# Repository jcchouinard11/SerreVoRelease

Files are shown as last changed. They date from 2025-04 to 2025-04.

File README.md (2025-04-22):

# SerreVo - Système de Gestion de Serre Intelligente

## Présentation
SerreVo est un projet de gestion automatisée de serre basé sur l'ESP32 et Arduino. Il permet le suivi et le contrôle des paramètres environnementaux pour optimiser la croissance des plantes.

## Fonctionnalités
- Surveillance en temps réel de la température, humidité
- Transmission des données via Bluetooth
- Interface web pour visualisation et réglages

## Structure du Répertoire
- **Documentation/** : Fichiers et guides du projet (Fichiers PCB)
- **Release/** : Code et fichiers finaux pour le projet (Codes serveur et controleurs)
- **.gitignore** : Fichiers à exclure du versionnement

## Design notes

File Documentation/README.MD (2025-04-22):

# README

## Description
Ce projet concerne le développement et la gestion d'un système centralisé pour la serre automatique. Il inclut la conception des schémas et circuits imprimés (PCB) ainsi que la gestion des tests unitaires.

---

## Structure des fichiers

### Dossiers
- `OutputReleaseV1SerreVo` : Contient la version de sortie du projet.

### Documentation et Tests
- `plan_de_tests_unitairesSerreVO.xlsx` : Plan détaillé des tests unitaires pour vérifier le bon fonctionnement des différentes parties du système.
- `README.md` : Ce fichier, expliquant la structure et l'utilisation du projet.

---

## Utilisation

1. Vérifier et modifier les schémas électroniques si nécessaire dans `SerreVo_Controller` et `SerreVo`.
2. Consulter `plan_de_tests_unitairesSerreVO.xlsx` tests unitaires pour s'assurer le bon fonctionnement du projet. 
3. Utiliser `OutputReleaseV1SerreVo` pour récupérer la version finale du projet.

---

## Remarques
- `SerreVo_Controller` et `SerreVo` contiennent les fichiers de conception des circuits imprimés.
- Assurez-vous que toutes les modifications aux PCB respectent les contraintes électriques et mécaniques du projet.
- Le plan de tests doit être suivi rigoureusement avant toute validation finale.

---

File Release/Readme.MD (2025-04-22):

# SerreVoRElease - Gestion de Serre avec ESP32 

## Description
SerreVo est un projet de gestion automatisée de serre utilisant un ESP32 et Arduino. Ce projet inclut également des fichiers de conception de PCB pour l'intégration matérielle finale.

## Structure du Répertoire
- **CodesControleur/** : Contient le firmware Arduino pour l'ESP32 Du controleur principal.
- **CodesEtFichiersServeurs/** : Fichiers de de la partie serveur.
- **.gitignore** : Fichier de configuration Git pour ignorer certains fichiers.
- **README.md** : Documentation du projet.

## Auteur
Projet SerreVo - Automatisation de serre intelligente.

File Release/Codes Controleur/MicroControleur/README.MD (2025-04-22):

# 📟 Projet de Gestion de Capteurs avec Affichage LVGL et BLE

Ce projet est une implémentation sur microcontrôleur permettant la gestion de plusieurs capteurs (température et humidité) via des bus I2C multiplexés, l'affichage des données sur un écran tactile avec LVGL, ainsi que la transmission Bluetooth Low Energy (BLE).

## 📌 Fonctionnalités

- **Gestion de capteurs multiples** : 
  - Supporte plusieurs bus I2C via `FlexWire`
  - Gestion de multiplexeurs pour l'ajout de plusieurs capteurs
  - Lecture des données depuis des capteurs `Adafruit_seesaw` et `SHT31`
- **Interface graphique avec LVGL** :
  - Affichage des mesures sur un écran TFT
  - Gestion tactile avec `XPT2046`
- **Communication BLE** :
  - Serveur BLE pour l'envoi des mesures vers un appareil mobile ou un ordinateur
  - Publicité BLE avec UUID spécifique
- **Gestion des tâches concurrentes** :
  - Synchronisation des accès aux capteurs avec `Semaphore`
  - Mise à jour de l'affichage et des données via `FreeRTOS`

## 🛠 Matériel Utilisé

- Microcontrôleur compatible avec **Arduino**
- Capteur de température et d'humidité **SHT31**
- Capteurs capacitifs **Adafruit Seesaw**
- Multiplexeur **I2C (TCA9548A ou équivalent)**
- Écran **TFT 240x320** avec contrôleur **ILI9341**
- Contrôleur tactile **XPT2046**
- Module **Bluetooth Low Energy (BLE)** intégré ou externe

## 🏗 Bibliothèques Requises

Avant de compiler, assure-toi d'installer les bibliothèques suivantes dans **Arduino IDE** ou **PlatformIO** :

- `FlexWire`
- `lvgl`
- `Adafruit_seesaw`
- `Adafruit_SHT31`
- `XPT2046_Touchscreen`
- `TFT_eSPI`
- `BLEDevice`

## 🚀 Installation et Compilation

1. **Cloner le projet** :
   ```sh
   git clone https://github.com/ton-repo/gestion-capteurs.git
   cd gestion-capteurs

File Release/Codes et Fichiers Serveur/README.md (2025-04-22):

# README

## Description
Cette partie du projet s'occupe de récupérer les donnés envoyés par BLE grâce à un bridge BLE/MQTT et les stocker dans une base de donné. Ces donnés sont alors afficher sur une page web à l'aide de Grafana
---

## Structure des fichiers

### Scripts Python
- `ScriptMQTT/MQTT_decodage.py` : Code principal qui récupère les données MQTT et les insère dans la base de données.
- `Grafana/dashboardSerreVO.json` : Ficher de dashboard pour import

### Bases de données SQLite
- `SerreVo` : Fichier de base de données principal utilisé pour stocker les informations.

### Documentation
- `README.md` : Ce fichier, expliquant la structure et l'utilisation du projet.

---

## Utilisation

1. Assurez-vous que votre broker MQTT est opérationnel et que le bridge BLE/MQTT envoie correctement les données.
2. Exécutez `MQTT_decodage.py` dans un terminal pour collecter et stocker les données.
3. Vous pourrez visualiser les données grâce à SQLite  studio ou Grafana.

---

---

Aidé par ChatGPT

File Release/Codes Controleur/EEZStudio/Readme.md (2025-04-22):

# Repertoire des fichiers EEZStudio 

Repertoire avec les fichiers de "UI" pour afficher et modifier l'écran LVGL

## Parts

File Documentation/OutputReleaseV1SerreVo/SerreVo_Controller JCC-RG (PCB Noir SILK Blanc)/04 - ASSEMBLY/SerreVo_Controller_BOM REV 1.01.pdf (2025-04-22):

Board | 1
Cours | 01

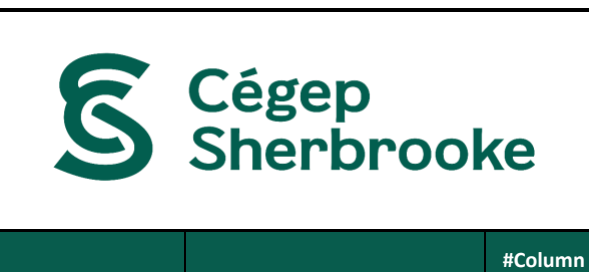
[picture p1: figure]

Item Number | Designator | Layer | Description | Comment | Package / Case | Supplier 1 | Supplier Part Number 1 | Quantity | Quantity Total | #Column Name Error:' Note
| C1, C7 | Top | CAP CER 0.1UF 16V X7R 0603 | 0.1 µF | 0603, 0603 (1608 Metric) | DigiKey | 478-KGM15AR71C104MMCT-ND, 399-5784-2-ND | 2 | 2
| C2, C5, C8, C9 | Top | CAP CER 0.012UF 16V X7R 0603 | 0.012 µF | 0603 (1608 Metric) | DigiKey | 311-3370-1-ND | 4 | 4
| C3 | Top | CAP ALUM 100UF 20% 10V SMD | 100 µF | Radial, Can - SMD | DigiKey | PCE3867CT-ND | 1 | 1
| C4 | Top | CAP CER 1UF 16V X7R 0603 | 1 µF | 0603 (1608 Metric) | DigiKey | 399-17719-1-ND | 1 | 1
| C6 | Top | CAP CER 22UF 6.3V X5R 0603 | 22µF | 0603 (1608 Metric) | DigiKey | 478-10812-1-ND | 1 | 1
| C10, C11 | Top | CAP CER 4.7UF 16V X6S 0603 | 4.7 µF | 0603 (1608 Metric) | DigiKey | 490-13362-1-ND | 2 | 2
| C12, C13, C14, C15, C16, C17, C18, C19 | Bottom | CAP CER 47UF 6.3V X5R 0603 | 47µF | 0603 (1608 Metric) | DigiKey | 478-11180-1-ND | 8 | 8
| D1 | Top | TVS DIODE 5.25V 17V SOT666 | USBLC6-2P6 | | | | 1 | 1
| D2 | Top | LED GREEN DIFFUSED 0603 SMD | Green | 0603 (1608 Metric) | DigiKey | 511-1579-1-ND | 1 | 1
| D3 | Top | LED RED DIFFUSED 1608 SMD | Red | 0603 (1608 Metric) | DigiKey | SML-D12U1WT86CT-ND | 1 | 1
| J1 | Top | CONN RCP USB2.0 TYP C 24P SMD RA | Usb-C | | | | 1 | 1
| J2, J3, J4, J5 | Top | Jack Modular Connector 8p8c _RJ45, Ethernet_ Vertical Unshielded Cat6 | SS-60000-007 | | | | 4 | 4
| J6 | Top | Connector Header Through Hole 10 position 0.098 (2.50mm) | B10B-XH-A(LF)(SN) | | | | 1 | 1
| J7 | Top | | B4B-XH-A | | | | 1 | 1
| Q1 | Top | MOSFET P-CHA 60V 720MW SOT23 | DMP6350S-7 | | | | 1 | 1
| R1, R2 | Top | RES 5.1KΩ 1.00% 0.1W 0603 | 5.1kohms | | | | 2 | 2
| R3, R4, R17, R18, R19, R20, R21, R22, R24, R25 | Top | RES SMD 30 OHM 5% 1/4W 0603 | 30 Ohms | 0603 (1608 Metric) | DigiKey | RHM30DCT-ND | 10 | 10

# Bill of Material

SerreVo Controleur | Concepteur Principal Jean-Christophe Chouinard
Projet TSO 2025 | Date du projet 2025-02-04
Technologies du génie électrique Département | Date de génération du BOM 2025-02-11
Révision 1.01 | Heure de génération du BOM 11:27
Nombre de PCB 1 | Variant None

Item Number | Designator | Layer | Description | Comment | Package / Case | Supplier 1 | Supplier Part Number 1 | Quantity | Quantity Total | #Column Name Error:' Note
| R5, R6, R29 | Top | RESA-AS 0603 0R JUMPER 100MW | 0 Ohms | 0603 (1608 Metric) | DigiKey | CR0603AJ/-000EASCT-ND | 3 | 3
| R7, R8, R9, R11, R12, R13, R14, R15, R16 | Top | RES SMD 330 OHM 1% 1/5W 0603 | 330 Ohms | 0603 (1608 Metric) | DigiKey | A129541CT-ND | 9 | 9
| R10, R23, R28 | Top | RES SMD 10K OHM 5% 1/4W 0603 | 10 kOhms | 0603 (1608 Metric) | DigiKey | 541-2817-1-ND | 3 | 3
| R26 | Top | RES SMD 220 OHM 1% 1/10W 0603 | 220 Ohms | 0603 (1608 Metric) | DigiKey | 118-CR0603-FX-2200ELFCT-ND | 1 | 1
| R27 | Top | RES SMD 470 OHM 1% 1/10W 0603 | 470 Ohms | 0603 (1608 Metric) | DigiKey | P470HCT-ND | 1 | 1
| SW1, SW2 | Top | SWITCH TACTILE SPST-NO 0.02A 15V | EVQ-Q2U01W | | | | 2 | 2
| U1 | Top | Bluetooth, WiFi 802.11b/g/n, Bluetooth v5.0 Transceiver Module 2.4GHz Antenna Not Included, U.FL Surface Mount | ESP32-S3-WROOM-1U-N16R8 | | | | 1 | 1
| U2, U3, U5, U6 | Top | Low Voltage I2C/SMBus Accelerator | LTC4311ISC6#TRPBF | | | | 4 | 4
| U4 | Top | No Description Available | R1172S331B-E2-FE | | | | 1 | 1

Commentaires ou instruction spécialies

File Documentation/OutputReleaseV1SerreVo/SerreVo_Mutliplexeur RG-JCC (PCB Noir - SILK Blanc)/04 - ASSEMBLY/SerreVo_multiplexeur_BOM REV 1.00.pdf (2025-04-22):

Board | 1
Cours | 00


Item Number | Designator | Layer | Description | Comment | Package / Case | Supplier 1 | Supplier Part Number 1 | Quantity | Quantity Total | #Column Name Error:' Note
| C1, C2, C3, C4, C8 | Top | CAP ALUM 47UF 20% 35V SMD | 47 µF | | DigiKey | 1572-476SML035MCT-ND | 5 | 5
| C5 | Bottom | CAP CER 1UF 16V X7R 0603 | 1 µF | 0603 (1608 Metric) | DigiKey | 399-17719-1-ND | 1 | 1
| C6, C7 | Bottom | CAP CER 4.7UF 25V X5R 0603 | 4.7 µF | 0603 (1608 Metric) | DigiKey | 1276-1900-1-ND | 2 | 2
| C9 | Top | CAP CER 22UF 6.3V X5R 0603 | 22µF | 0603 (1608 Metric) | DigiKey | 478-10812-1-ND | 1 | 1
| C10 | Top | CAP CER 0.1UF 16V X7R 0603 | 0.1 µF | 0603 (1608 Metric) | DigiKey | 399-5784-2-ND | 1 | 1
| J1, J2, J3, J4, J5 | Top | Jack Modular Connector 8p8c _RJ45, Ethernet_ Vertical Unshielded Cat6 | SS-60000-007 | | | | 5 | 5
| R1 | Top | RES ARRAY 8 RES 33 OHM 2506 | 742C163330JP | 2506, Concave, Long Side Terminals | DigiKey | 742C163330JPCT-ND | 1 | 1
| R2 | Top | RES ARRAY 8 RES 330 OHM 2506 | 742C163331JP | 2506, Concave, Long Side Terminals | DigiKey | 742C163331JPCT-ND | 1 | 1
| R3 | Top | RES SMD 10K OHM 5% 1/4W 0603 | 10 kOhms | 0603 (1608 Metric) | DigiKey | 541-2817-1-ND | 1 | 1
| U1 | Top | IC I2C SW 8CH W/RESET 24TSSOP | TCA9548APWR | | | | 1 | 1
| U2 | Top | No Description Available | R1172S331B-E2-FE | | | | 1 | 1

Commentaires ou instruction spécialies

# Bill of Material

SerrVo_multiplexeur | Concepteur Principal Raphaël Gravel
Projet final | Date du projet 2025-02-04
Technologies du génie électrique Département | Date de génération du BOM 2025-02-11
Révision 1.00 | Heure de génération du BOM 09:09
Nombre de PCB 1 | Variant None

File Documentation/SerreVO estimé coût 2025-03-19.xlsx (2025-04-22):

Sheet: Controleur
Titre du projet
Projet TSO: SerreVO Controleur
Demandeur(s) : Prof responsabe et étudiants
Nicolas Huppé (Jean-Christophe Chouinard / Raphaël Gravel)
Moment où le matériel est NÉCESSAIRE
2025-03-12
Identification des cours qui sont impactés
247-575-SH
Lien(s) vers document de soumission (si applicable)
Liste des éléments associés
Description | Prix unitaire | Taux change (1 par défaut $Can) | Quantité demandée | Total item | Fournisseur | # Modèle pour commande | Hyperlien pour commande (si disponible) ou soumission | Commentaires et/ou autres informations | Colonne réservée pour suivi des commandes
Factory Orginal 3.2" 240*320 ILI9341 | 12.68 $ | 1.00 | 1 | 12.68 $ | Aliexpress |  | https://www.aliexpress.com/item/1005004581389736.html?utparam-url=scene%3Asearch%7Cquery_from%3A
IP68 RJ45 CAT7 Connector Waterproof M23 | 4.04 $ | 1.00 | 4 | 16.16 $ | aliexpress | YPM23-CAT7-B | https://www.aliexpress.com/item/1005007377576378.html?utparam-url=scene%3Asearch%7Cquery_from%3A
Adafruit STEMMA Soil Sensor | 10.74 $ | 1.00 | 4 | 42.96 $ | Adafruit | 4026 | https://www.adafruit.com/product/4026
Câble USB C de 1 m Flat | 11.99 $ | 1.00 | 1 | 11.99 $ | Amazon | B0CPDZBH62 | https://www.amazon.ca/-/fr/gp/product/B0CPDZBH62/ref=ox_sc_act_title_6?smid=A3QJI6T39D7L77
Mâle Femelle Surmoulé Câble USB C type C | 3.71 $ | 1.00 | 2 | 7.42 $ | Alibaba |  | https://www.alibaba.com/product-detail/Speed-3-0-3-1-Panel_1600925654612.html?s=p
SHT30 TEMPERATURE AND HUMIDITY S | 13.60 $ | 1.00 | 1 | 13.60 $ | Adafruit | 5064 | https://www.digikey.ca/en/products/detail/adafruit-industries-llc/5064/14625562?productid=14625562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
Boîte de jonction en plastique ABS étanche à la poussière IP65 | 21.99 $ | 1.00 | 1 | 21.99 $ | Amazon | B07KXSPRGC | https://www.amazon.ca/-/fr/gp/product/B07KXSPRGC/ref=ox_sc_saved_title_6?smid=
Coût PCB Controleur | 60.00 $ | 1.00 | 1 | 60.00 $ | Digikey |  | https://www.digikey.ca/en/mylists/list/ZFMKY3XMLB
Cables variées et connecteurs | 10.00 $ | 1.00 | 1 | 10.00 $
 |  | 1.00 |  | 0.00 $
 |  | 1.00 |  | 0.00 $
 |  | 1.00 |  | 0.00 $
 |  | 1.00 |  | 0.00 $
 |  | 1.00 |  | 0.00 $
 |  | 1.00 |  | 0.00 $
 |  | 1.00 |  | 0.00 $
 |  | 1.00 |  | 0.00 $
 |  | 1.00 |  | 0.00 $
 |  | 1.00 |  | 0.00 $
 |  | 1.00 |  | 0.00 $
 |  | 1.00 |  | 0.00 $
 |  | 1.00 |  | 0.00 $
 |  | 1.00 |  | 0.00 $
 |  | 1.00 |  | 0.00 $
 |  | 1.00 |  | 0.00 $
 |  | 1.00 |  | 0.00 $
 |  | 1.00 |  | 0.00 $
 |  | 1.00 |  | 0.00 $
 |  | 1.00 |  | 0.00 $
 |  |  | Total sans taxes | 196.80 $
 |  |  | Taxe 7% | 13.78 $
 |  |  | Total avec taxes | 210.58 $
 |  |  | Total avec marge 20% | 252.69 $

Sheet: Multiplexeur
Titre du projet
Projet TSO: SerreVO Controleur
Demandeur(s) : Prof responsabe et étudiants
Nicolas Huppé (Jean-Christophe Chouinard / Raphaël Gravel)
Moment où le matériel est NÉCESSAIRE
2025-03-12
Identification des cours qui sont impactés
247-575-SH
Lien(s) vers document de soumission (si applicable)
Liste des éléments associés
Description | Prix unitaire | Taux change (1 par défaut $Can) | Quantité demandée | Total item | Fournisseur | # Modèle pour commande | Hyperlien pour commande (si disponible) ou soumission | Commentaires et/ou autres informations | Colonne réservée pour suivi des commandes
IP68 RJ45 CAT7 Connector Waterproof M23 | 4.04 $ | 1.00 | 5 | 20.20 $ | aliexpress | YPM23-CAT7-B | https://www.aliexpress.com/item/1005007377576378.html?utparam-url=scene%3Asearch%7Cquery_from%3A
Boîte de jonction en plastique ABS étanche à la poussière IP65 | 21.99 $ | 1.00 | 1 | 21.99 $ | Amazon | B07KXSPRGC | https://www.amazon.ca/-/fr/gp/product/B07KXSPRGC/ref=ox_sc_saved_title_6?smid=
Cout PCB Multiplexeur | 30.00 $ | 1.00 | 1 | 30.00 $ | Digikey |  | https://www.digikey.ca/en/mylists/list/KLJ95604RC
Cables variées et connecteurs | 5.00 $ | 1.00 | 1 | 5.00 $
 |  | 1.00 |  | 0.00 $
 |  | 1.00 |  | 0.00 $
 |  | 1.00 |  | 0.00 $
 |  | 1.00 |  | 0.00 $
 |  | 1.00 |  | 0.00 $
 |  | 1.00 |  | 0.00 $
 |  | 1.00 |  | 0.00 $
 |  | 1.00 |  | 0.00 $
 |  | 1.00 |  | 0.00 $
 |  | 1.00 |  | 0.00 $
 |  | 1.00 |  | 0.00 $
 |  | 1.00 |  | 0.00 $
 |  | 1.00 |  | 0.00 $
 |  | 1.00 |  | 0.00 $
 |  | 1.00 |  | 0.00 $
 |  | 1.00 |  | 0.00 $
 |  | 1.00 |  | 0.00 $
 |  | 1.00 |  | 0.00 $
 |  | 1.00 |  | 0.00 $
 |  | 1.00 |  | 0.00 $
 |  |  | Total sans taxes | 77.19 $
 |  |  | Taxe 7% | 5.40 $
 |  |  | Total avec taxes | 82.59 $
 |  |  | Total avec marge 20% | 99.11 $

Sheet: Capteurs
Titre du projet
Projet TSO: SerreVO Controleur
Demandeur(s) : Prof responsabe et étudiants
Nicolas Huppé (Jean-Christophe Chouinard / Raphaël Gravel)
Moment où le matériel est NÉCESSAIRE
2025-03-12
Identification des cours qui sont impactés
247-575-SH
Lien(s) vers document de soumission (si applicable)
Liste des éléments associés
Description | Prix unitaire | Taux change (1 par défaut $Can) | Quantité demandée | Total item | Fournisseur | # Modèle pour commande | Hyperlien pour commande (si disponible) ou soumission | Commentaires et/ou autres informations | Colonne réservée pour suivi des commandes
Adafruit STEMMA Soil Sensor | 10.74 $ | 1.00 | 1 | 10.74 $ | Adafruit | 4026 | https://www.adafruit.com/product/4026
Cables variées et connecteurs | 2.00 $ | 1.00 | 1 | 2.00 $
 |  | 1.00 |  | 0.00 $
 |  | 1.00 |  | 0.00 $
 |  | 1.00 |  | 0.00 $
 |  | 1.00 |  | 0.00 $
 |  | 1.00 |  | 0.00 $
 |  | 1.00 |  | 0.00 $
 |  | 1.00 |  | 0.00 $
 |  | 1.00 |  | 0.00 $
 |  | 1.00 |  | 0.00 $
 |  | 1.00 |  | 0.00 $
 |  | 1.00 |  | 0.00 $
 |  | 1.00 |  | 0.00 $
 |  | 1.00 |  | 0.00 $
 |  | 1.00 |  | 0.00 $
 |  | 1.00 |  | 0.00 $
 |  | 1.00 |  | 0.00 $
 |  | 1.00 |  | 0.00 $
 |  | 1.00 |  | 0.00 $
 |  | 1.00 |  | 0.00 $
 |  | 1.00 |  | 0.00 $
 |  |  | Total sans taxes | 12.74 $
 |  |  | Taxe 7% | 0.89 $
 |  |  | Total avec taxes | 13.63 $
 |  |  | Total avec marge 20% | 16.36 $

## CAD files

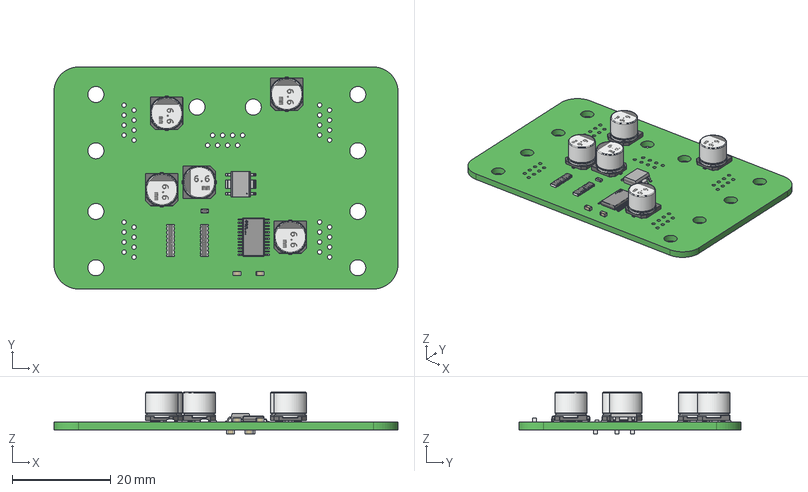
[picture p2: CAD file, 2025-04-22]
Documentation/OutputReleaseV1SerreVo/SerreVo_Mutliplexeur RG-JCC (PCB Noir - SILK Blanc)/05 - 3D MODEL/SerreVo_multiplexeur_PCB REV 1.00.step
69.8 x 45.1 x 8.48 mm
0603 cap x 5
0603 resistor
CAP ALSMD - 6.6 x 6.6 x 6.1 x 5
RESNET - 2506 Concave x 2
BODY-TSSOP
LEAD-TSSOP x 24
Texas Logo Yury
Texas Logo Yury - 1

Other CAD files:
Documentation/OutputReleaseV1SerreVo/SerreVo_Mutliplexeur RG-JCC (PCB Noir - SILK Blanc)/05 - 3D MODEL/SerreVo_multiplexeur_PCB REV 1.00.x_t

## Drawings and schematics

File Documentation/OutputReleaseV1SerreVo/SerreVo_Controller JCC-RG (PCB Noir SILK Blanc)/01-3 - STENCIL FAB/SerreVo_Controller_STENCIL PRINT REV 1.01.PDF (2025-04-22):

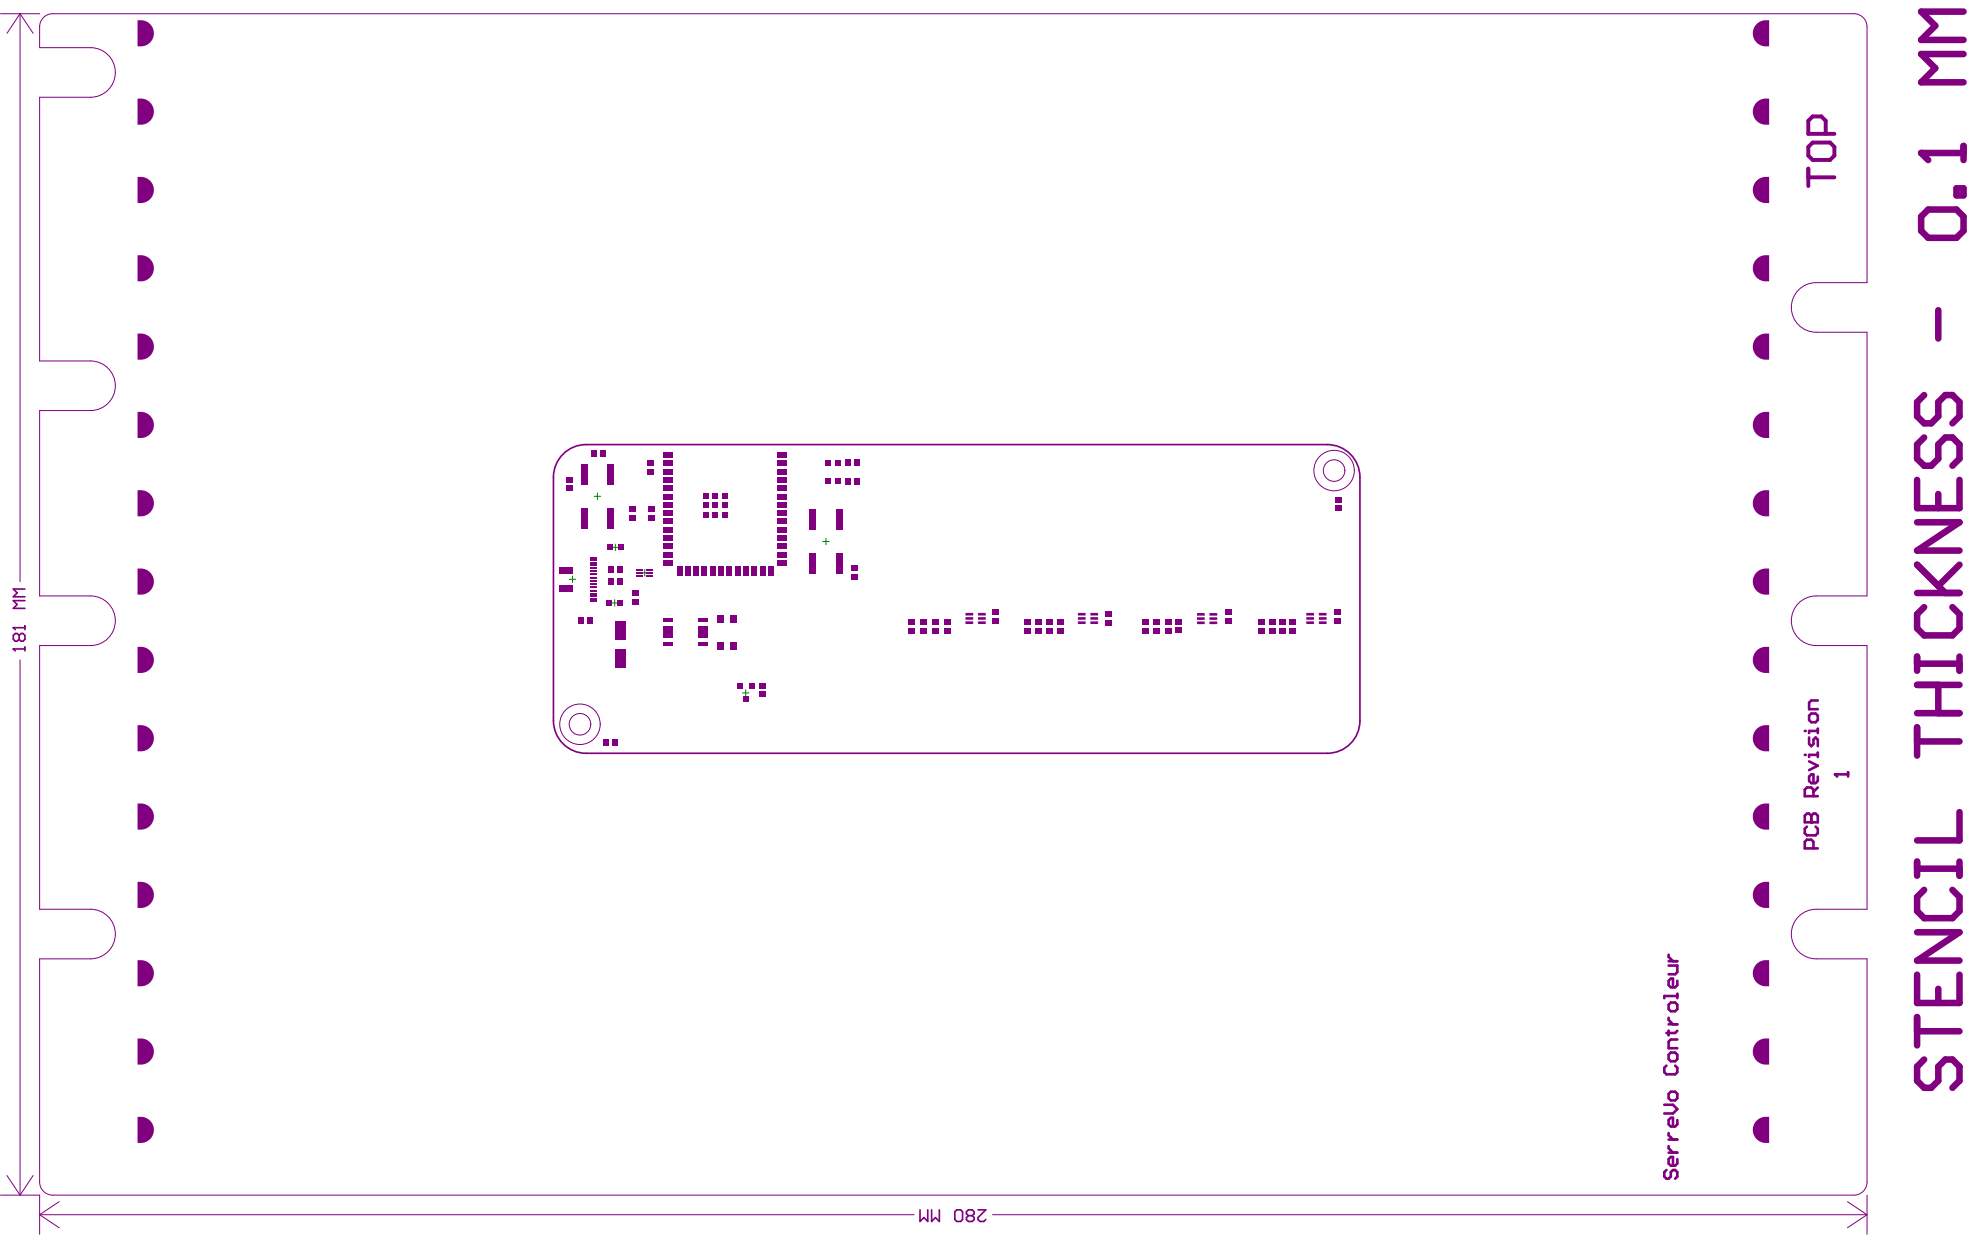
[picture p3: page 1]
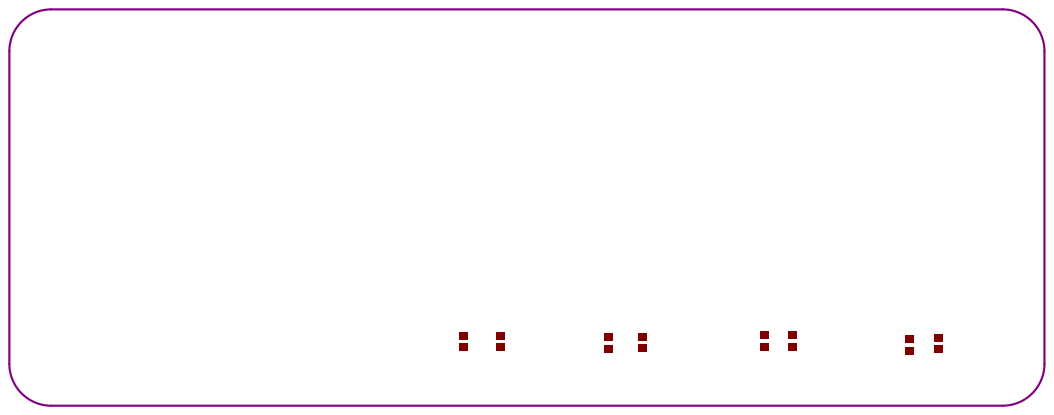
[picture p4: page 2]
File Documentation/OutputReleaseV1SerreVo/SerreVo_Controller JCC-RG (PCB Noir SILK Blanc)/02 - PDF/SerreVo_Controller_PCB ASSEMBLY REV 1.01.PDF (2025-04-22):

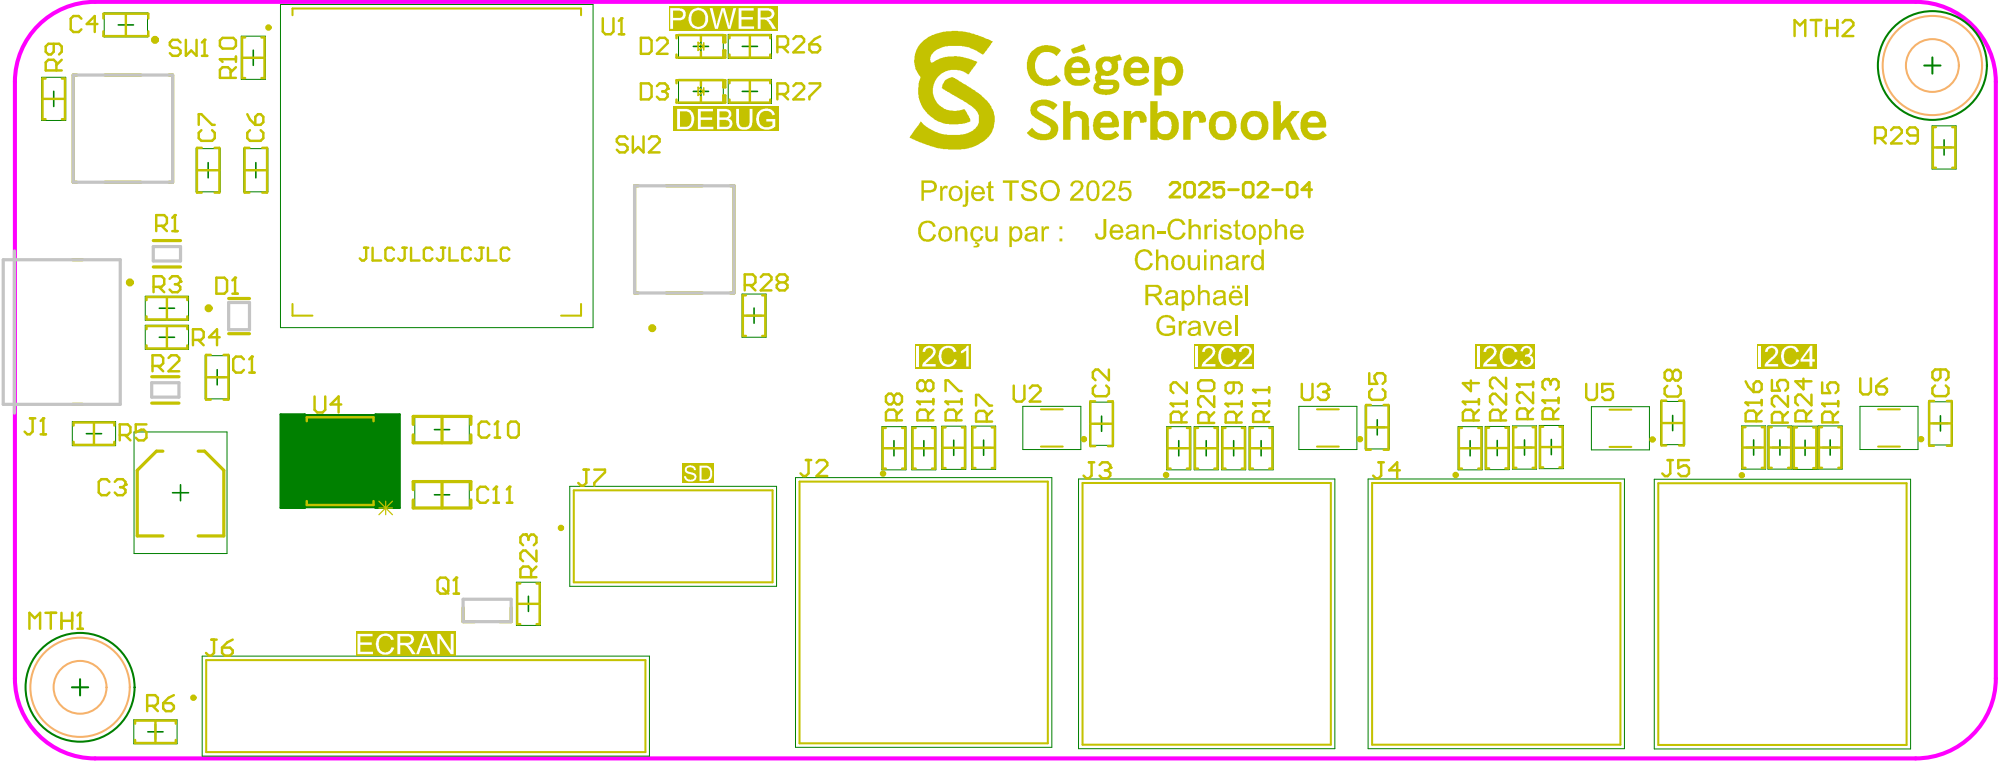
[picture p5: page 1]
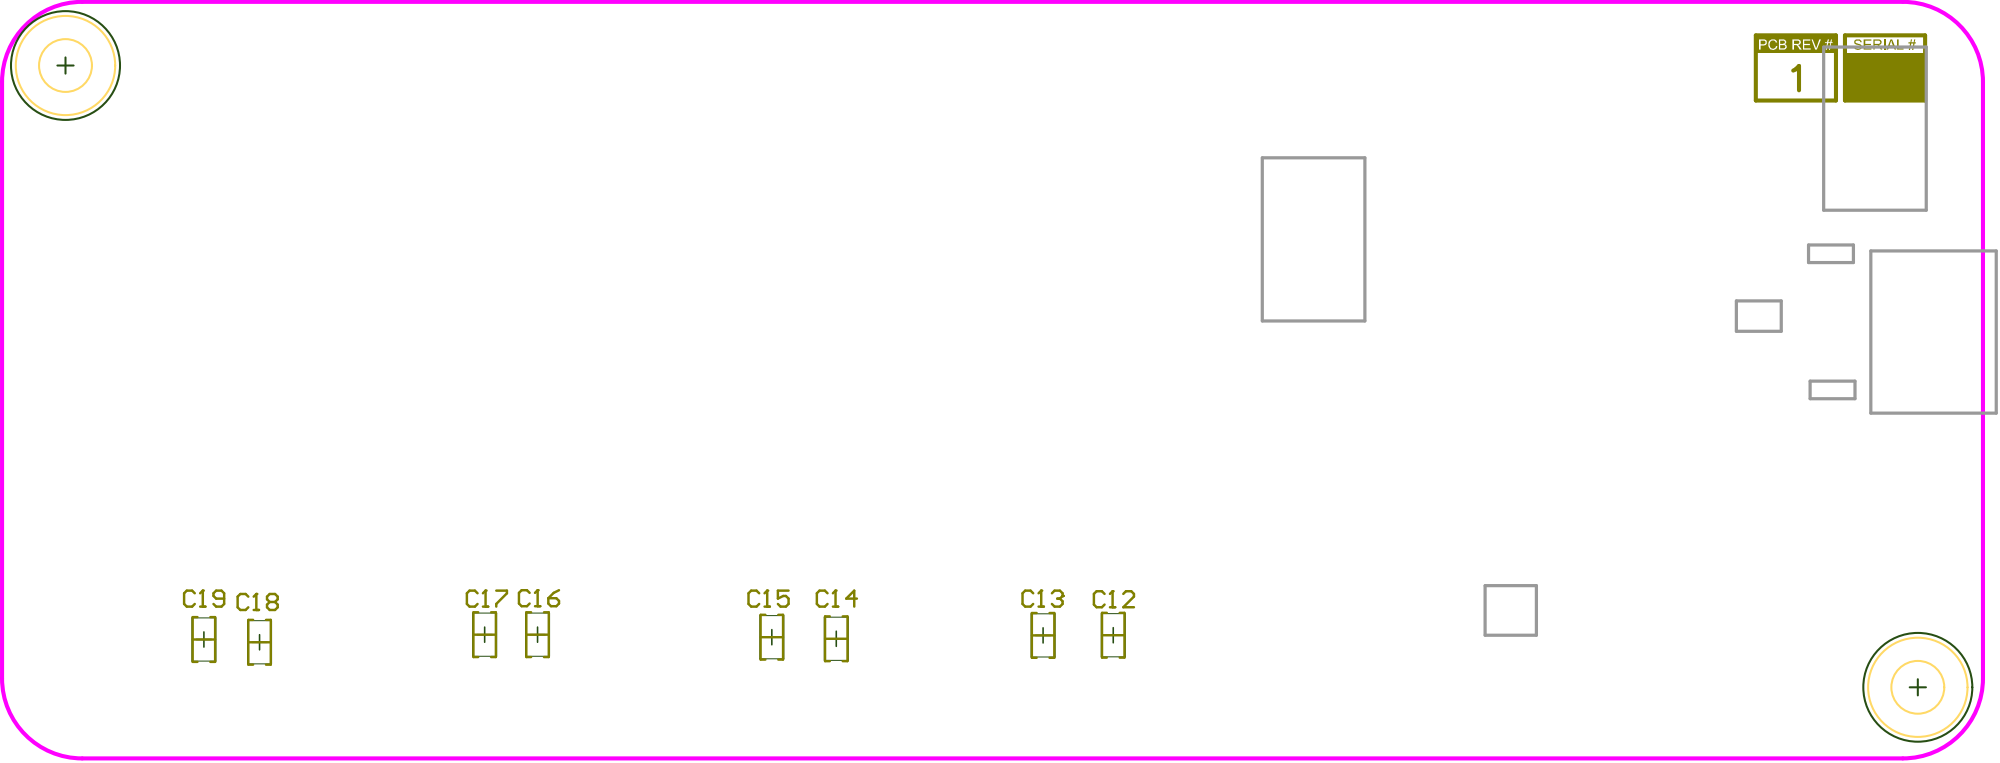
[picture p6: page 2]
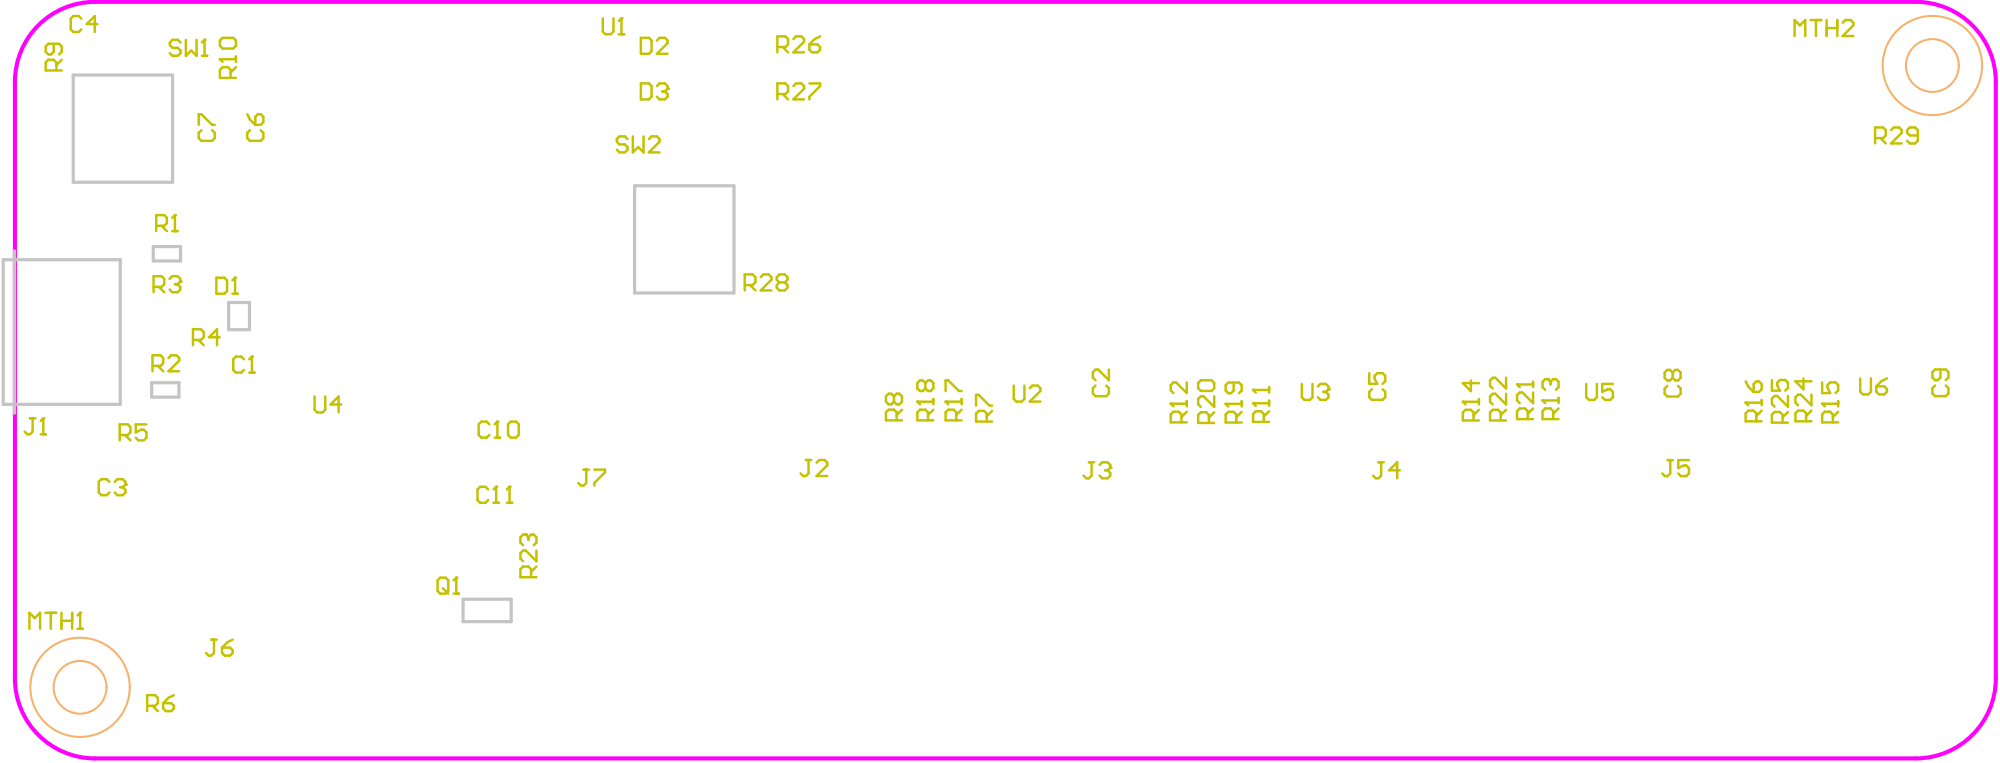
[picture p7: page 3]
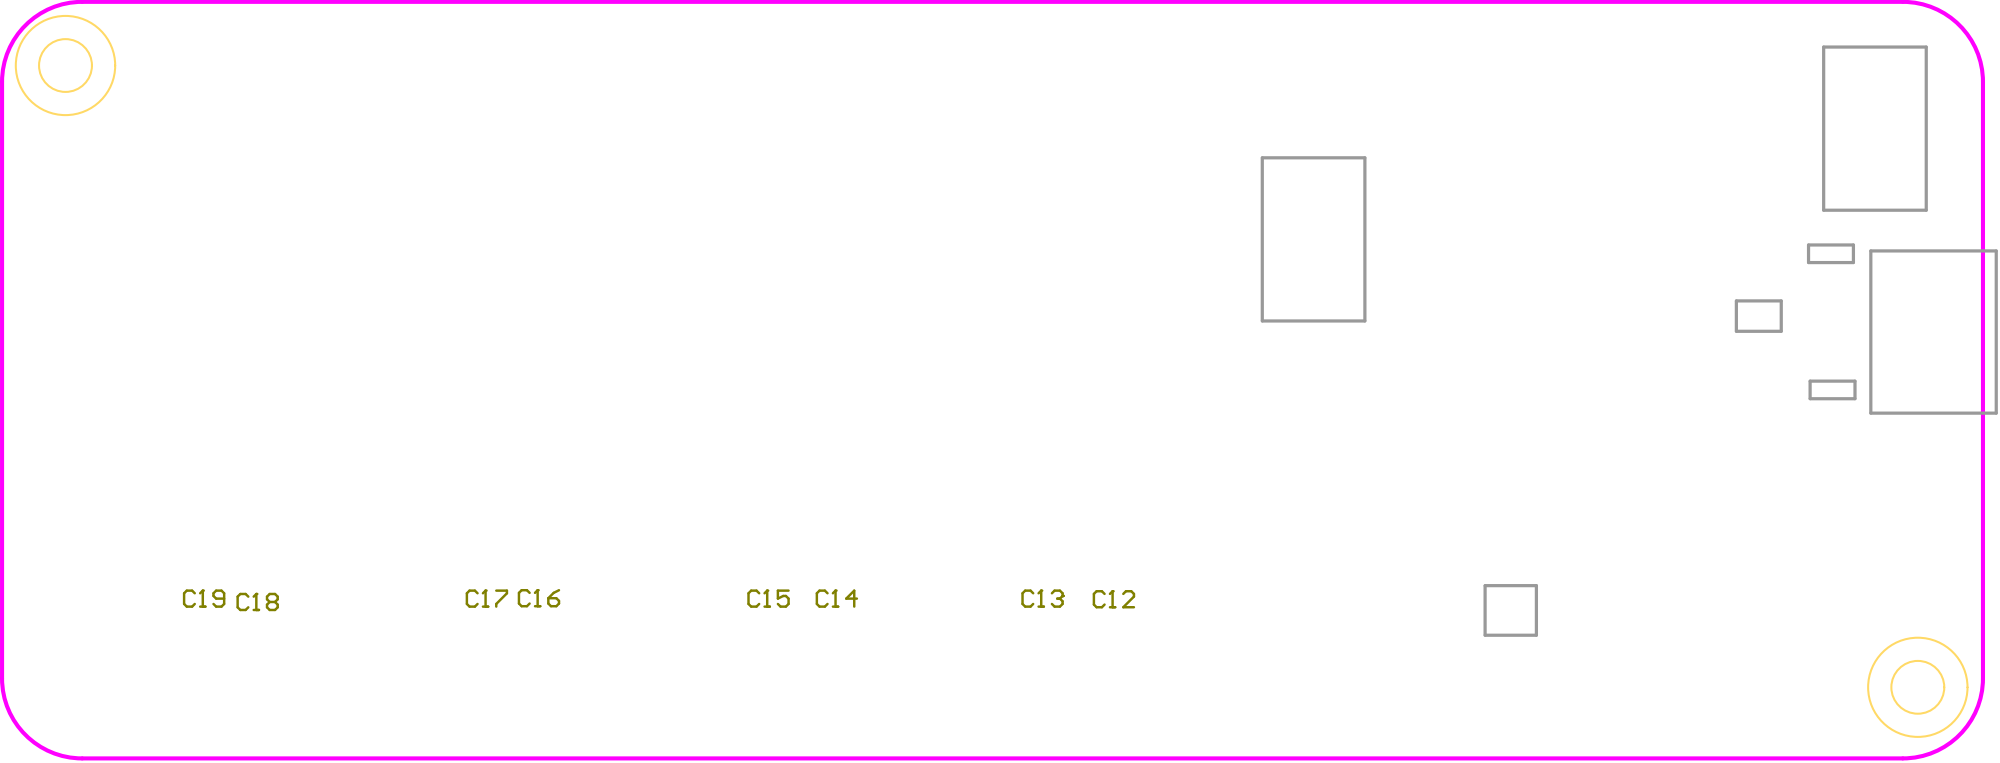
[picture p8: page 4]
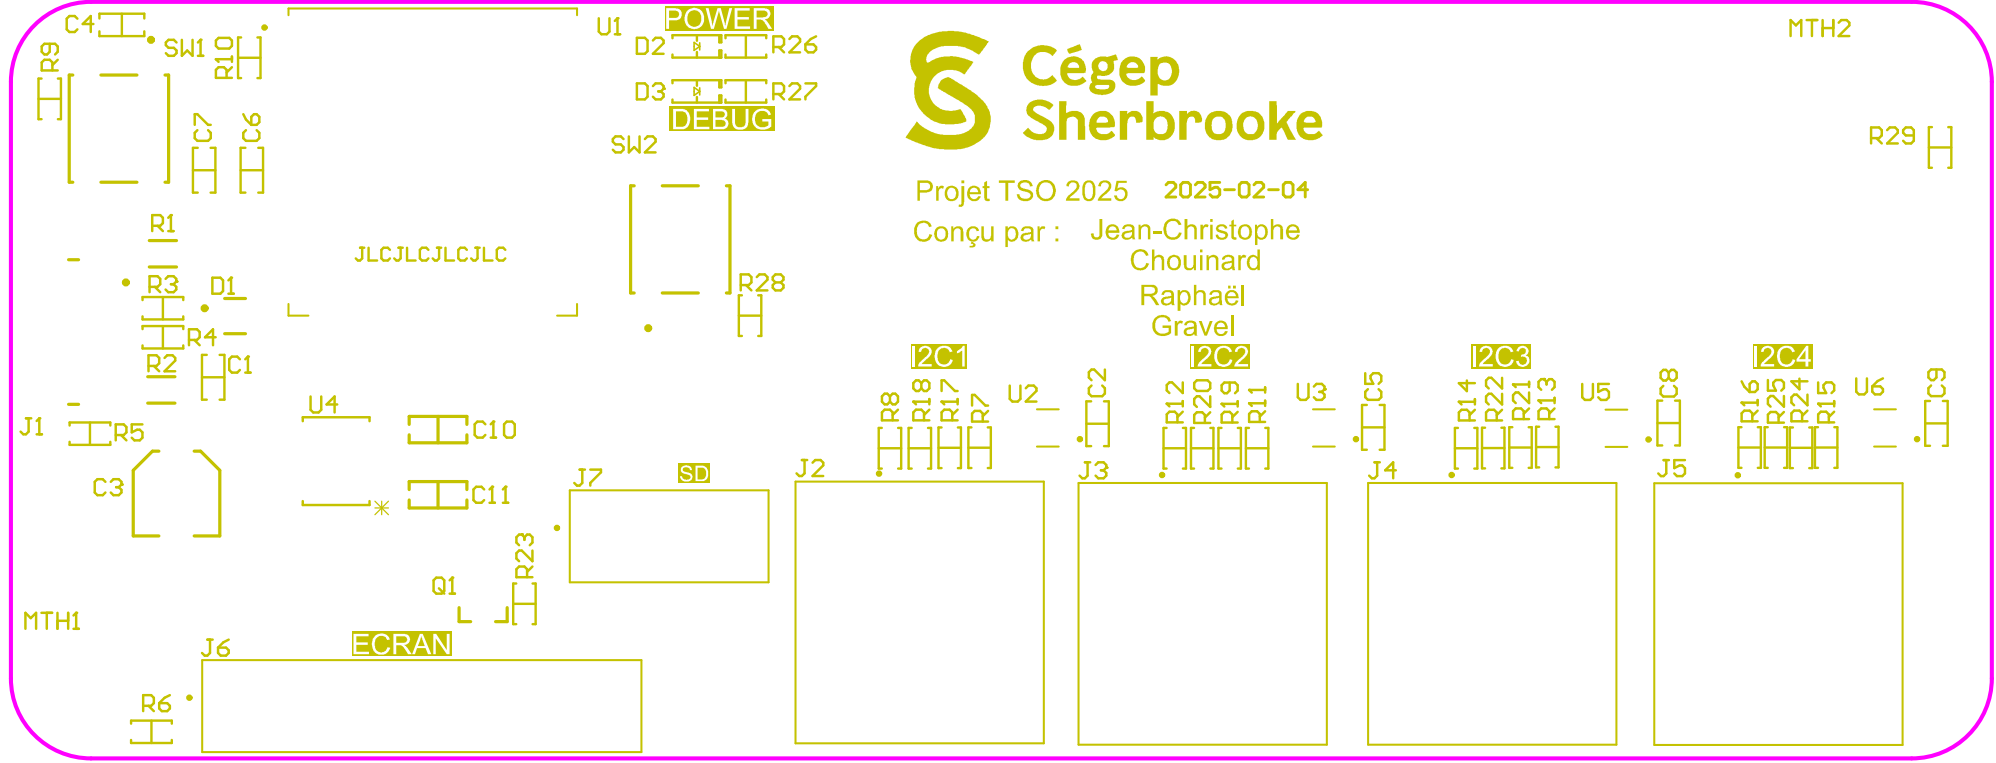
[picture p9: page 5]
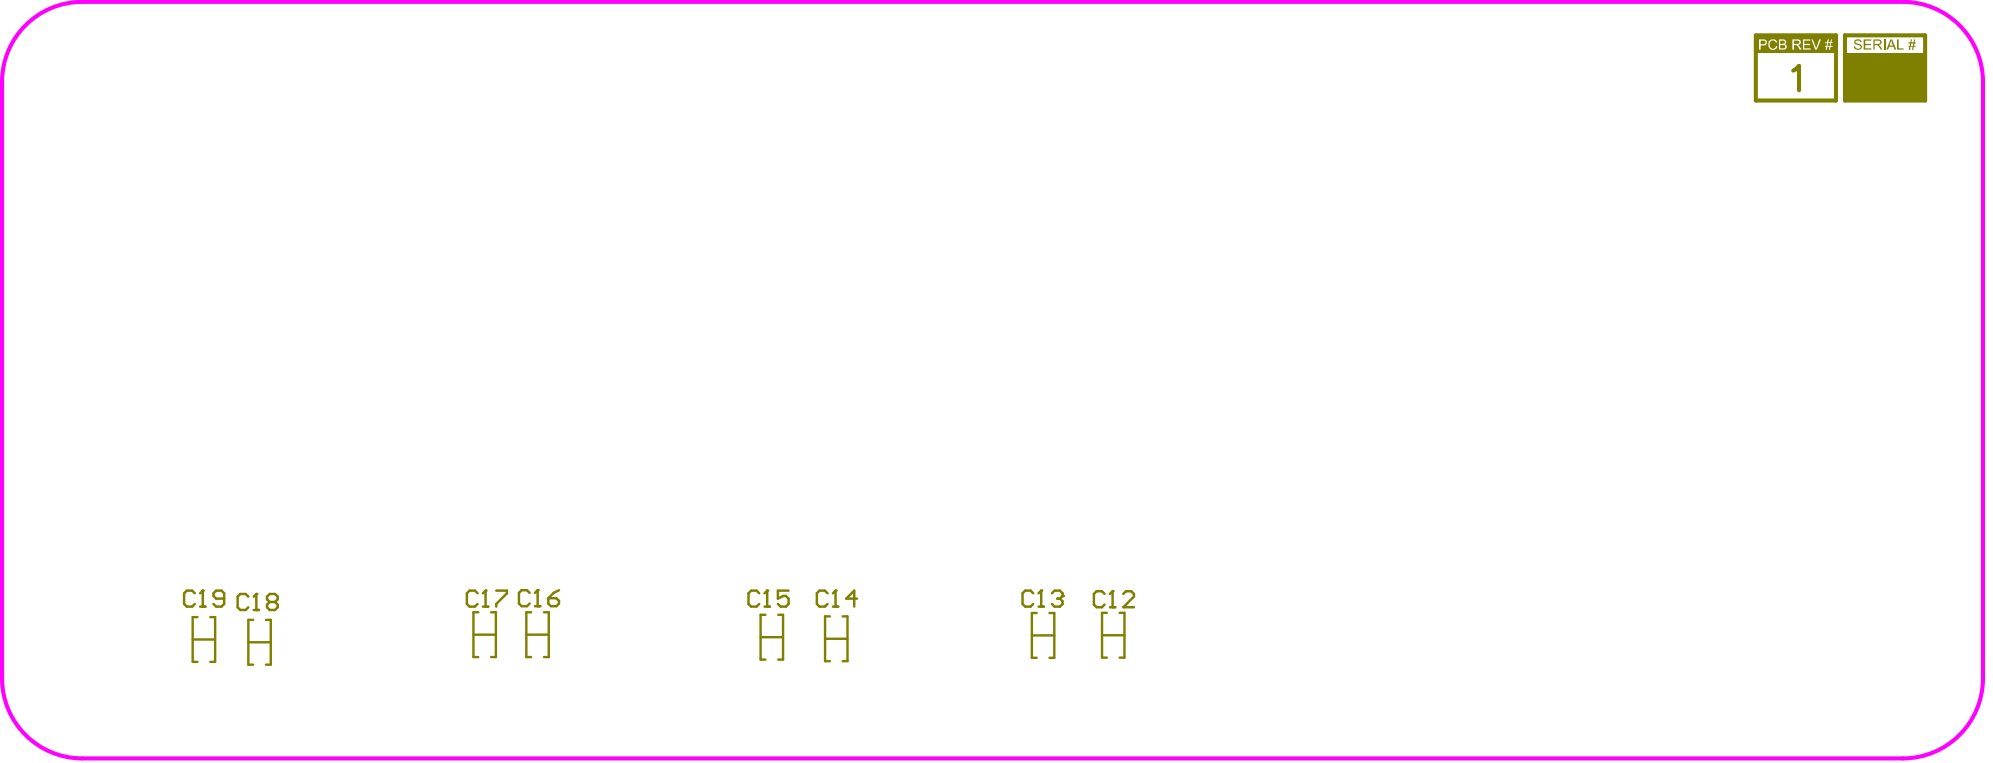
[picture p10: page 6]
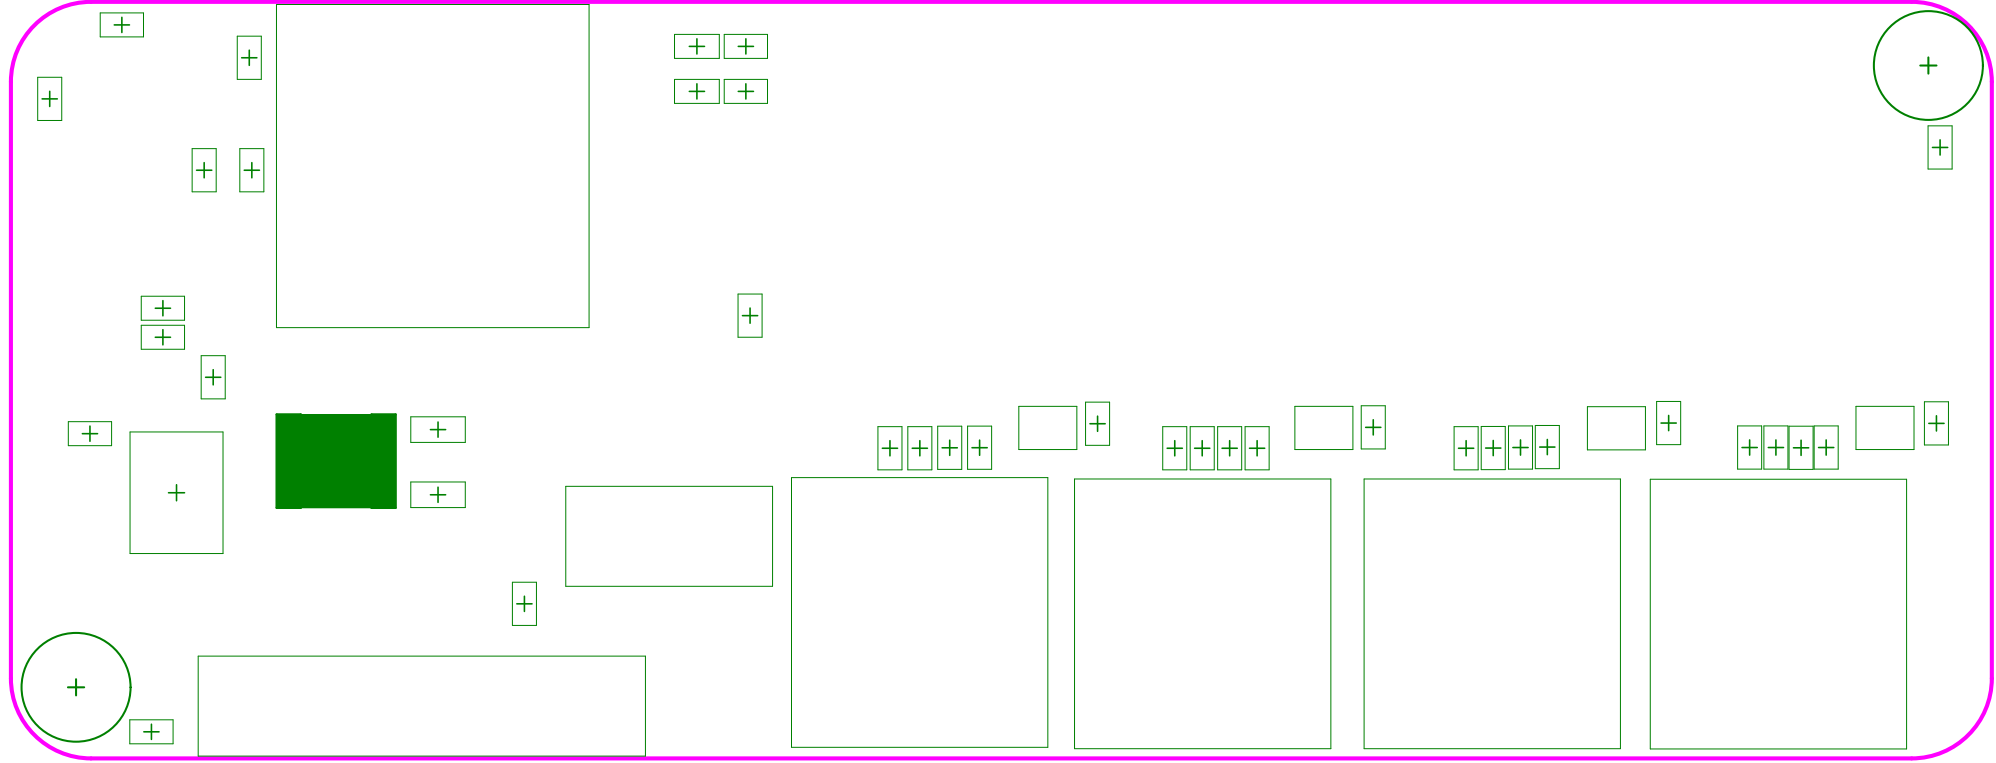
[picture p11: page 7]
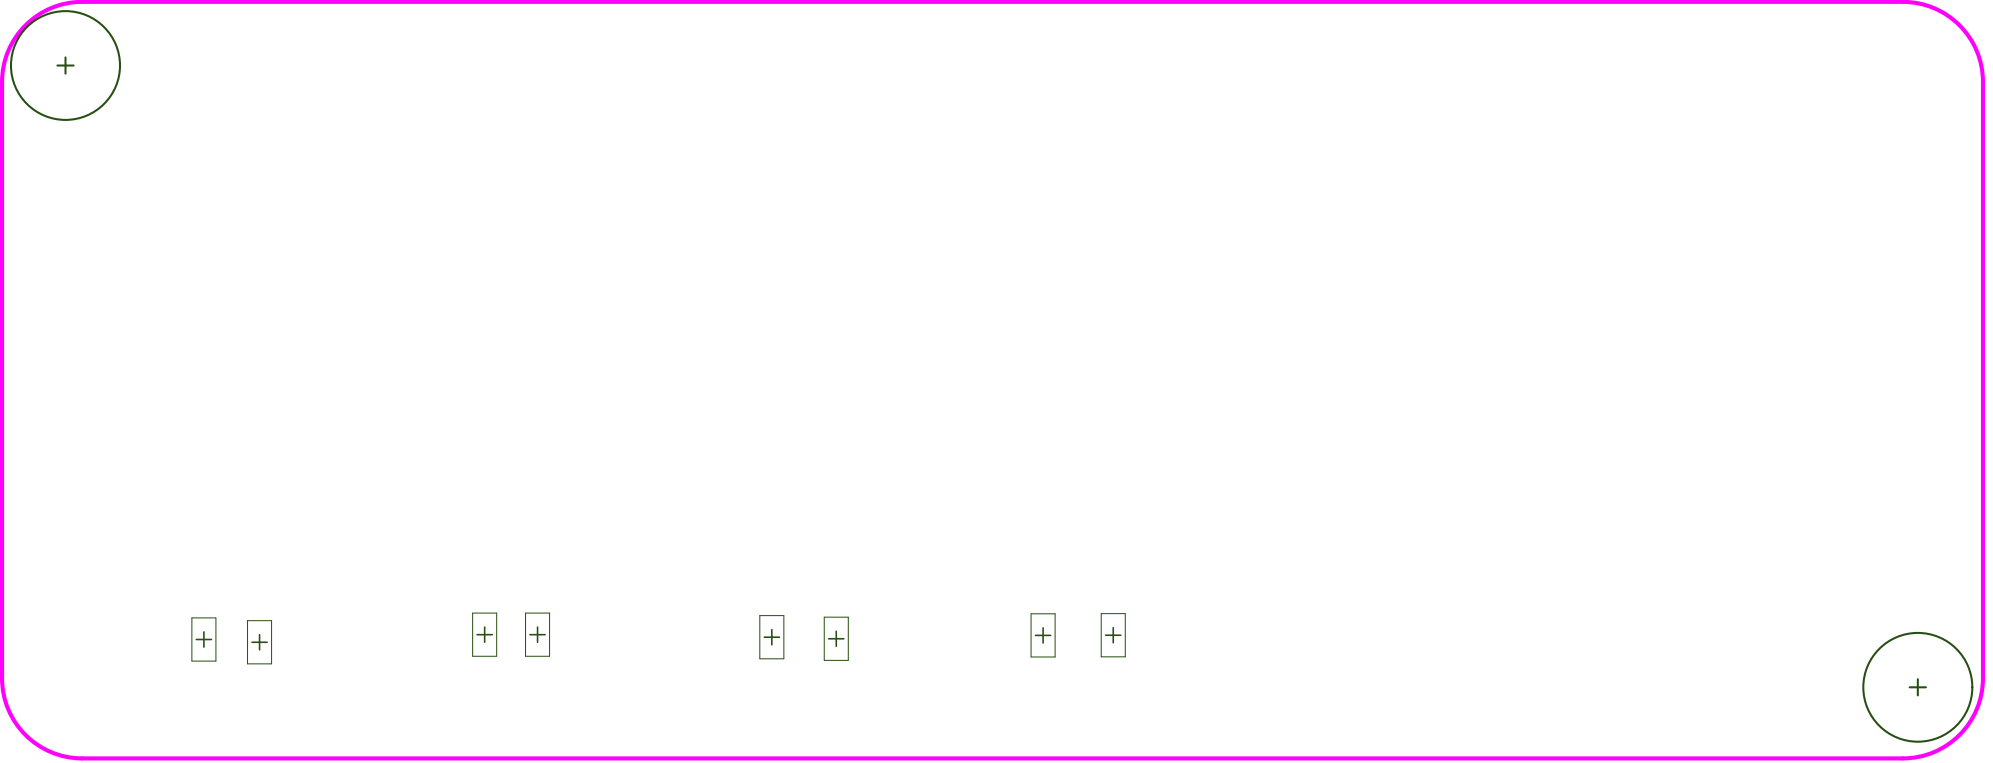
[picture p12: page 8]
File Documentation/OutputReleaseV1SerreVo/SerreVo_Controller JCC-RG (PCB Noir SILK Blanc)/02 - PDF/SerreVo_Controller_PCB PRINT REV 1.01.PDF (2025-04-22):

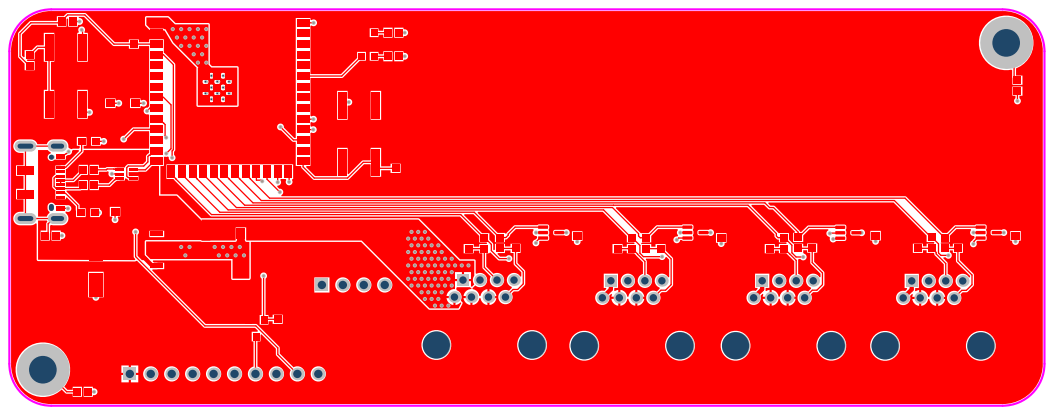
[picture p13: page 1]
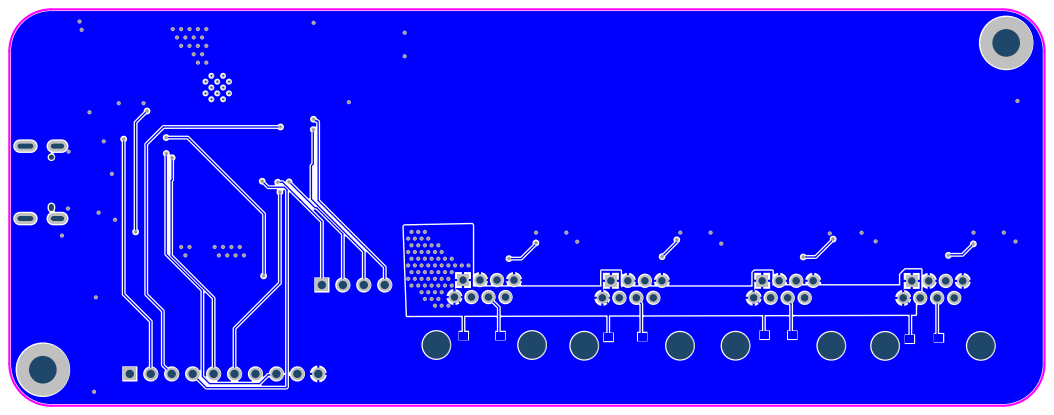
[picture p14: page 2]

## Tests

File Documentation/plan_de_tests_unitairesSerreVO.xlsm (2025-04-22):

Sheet: TestPCBMultiplexeur
 | Plan de tests
Board | Manette Projet Final | Testeur | JC.C,R.G
Cours |  | Date des tests | 2024-12-09
Département | TGÉ
Révision | 1.0
Fonction | Test | Résultat | Commentaires
Test de court-circuit | Vérifier les courts-circuits entre les lignes de tension et la masse. |  |  | NOTE : Voir la TestHardware si le test 10 a 28 est faux
Test de court-circuit
Test de consommation d'énergie | Vérifier que la consommation de courant ne dépasse pas la consommation spécifiée pour chaque module.
Test de consommation d'énergie | Vérifier que la consommation de courant ne dépasse pas la consommation spécifiée pour chaque module.
Test des niveaux de tension | Vérifier que toutes les lignes de tension (3.3V, 5V) fournissent la bonne tension.
Test des niveaux de tension | Vérifier que toutes les lignes de tension (3.3V, 5V) fournissent la bonne tension.
Integrité
Vérification de l'affectation des broches | Vérifier que chaque broche est connectée à son composant correspondant comme prévu.
Vérification de la mise à la terre | Vérifier que toutes les broches de masse sont correctement connectées au plan de masse.
Test de communication ESP32 | Vérifier que les protocoles de communication (SPI/I2C)fonctionnent correctement sur les ports Ethernet.

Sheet: TestPCBControleur
 | Plan de tests
Board | Projet Final TSO | Testeur | JCC R.G
Cours |  | Date des tests
Département | TGÉ
Révision | 1.0
Fonction | Test | Résultat | Commentaires
Test des niveaux de tension | Vérifier que toutes les lignes de tension (3.3V, 5V) fournissent la bonne tension.
Test des niveaux de tension | Vérifier que toutes les lignes de tension (3.3V, 5V) fournissent la bonne tension.
Test de consommation d'énergie | Vérifier que la consommation de courant ne dépasse pas la consommation spécifiée pour chaque module.
Test de consommation d'énergie | Vérifier que la consommation de courant ne dépasse pas la consommation spécifiée pour chaque module.
Test de court-circuit | Vérifier les courts-circuits entre les lignes de tension et la masse.
Test de court-circuit
Vérification de l'affectation des broches | Vérifier que chaque broche est connectée à son composant correspondant comme prévu.
Vérification de l'affectation des broches
Vérification de la mise à la terre | Vérifier que toutes les broches de masse sont correctement connectées au plan de masse.
Test de communication ESP32 | Verifier la bonne programation Via le port USB
Test de communication ESP32 | Vérifier que les protocoles de communication (SPI/I2C/BLE)de l'ESP32 fonctionnent correctement.

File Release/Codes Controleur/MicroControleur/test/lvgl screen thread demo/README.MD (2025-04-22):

Code Platform io ESP-32-S3
Code avec Ecran ili9341 et un capteur de sol et un capteur ambiant 

Code avec deux coeurs.
